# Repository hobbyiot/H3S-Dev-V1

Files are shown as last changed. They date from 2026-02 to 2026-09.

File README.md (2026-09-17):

# H3S-Dev board for building Meshtastic nodes

### The new H3S-Dev design is now in pilot production!

#
## This project is being sponsored by [PCBWay](https://www.pcbway.com/)
### They offer a turnkey service to manufacture and assemble your printed circuit boards! The whole operation is fast and reliable since every single step is agreed between the customer and the responsible people from the factory. Every one detail is discussed as the components and materials used are agreed on at a high professional level.
#

### Specifications:
-  MCU:  ESP32-S3 with 8MB PSRAM
-  LoRa: RA-01SH-P with Power amplifier
-  GNSS: L96-M33 or similar
-  Power: USB-C and additional input (for example solar source) with separate sensing
-  LiPo battery management
-  I2C extension slots and soldering area
-  Credit card size 2-layer PCB
-  KiCad design open source hardware
#

### As a successor of our recent [H2S-Dev board](https://github.com/hobbyiot/LoRa-Nodes) the new hardware is compatible with both Meshtastic and Helium networks, ready to setup a simple node, sensor or tracker of your choice!

#
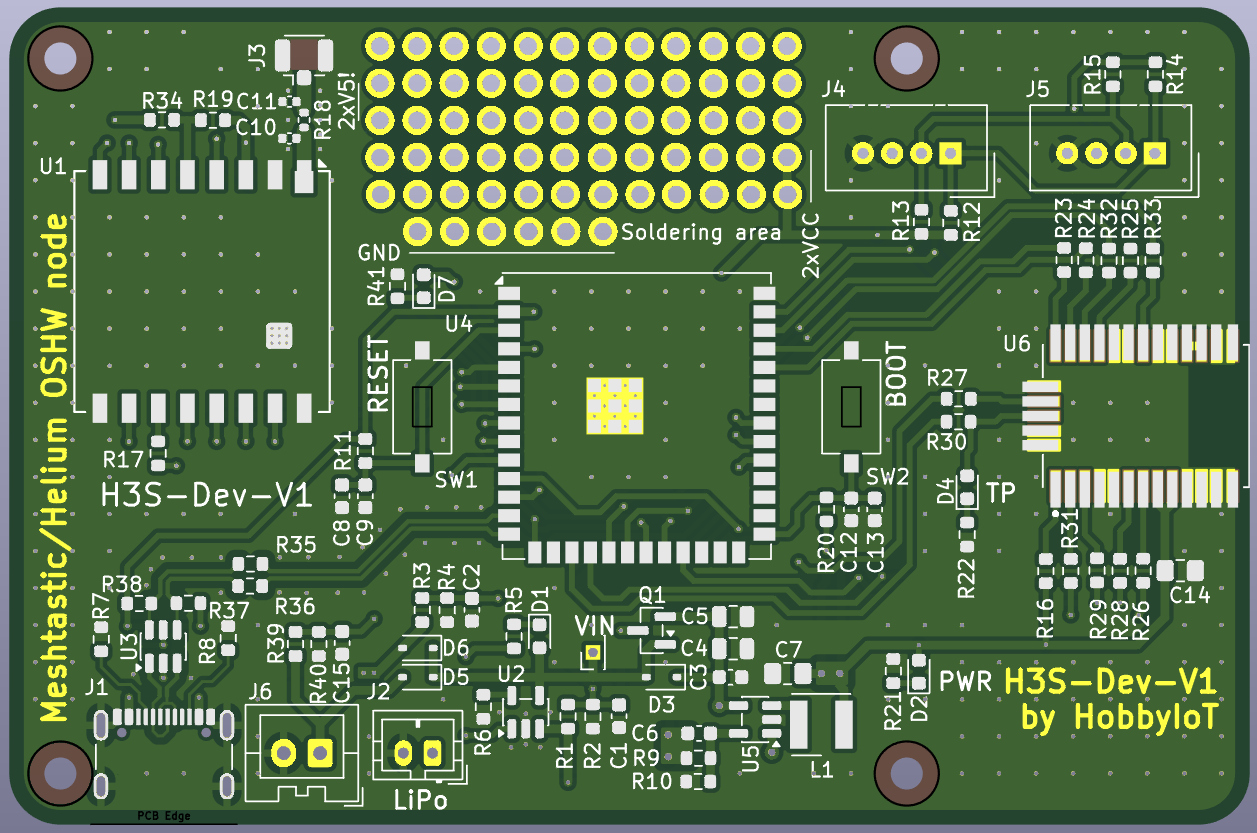
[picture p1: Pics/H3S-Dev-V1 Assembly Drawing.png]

#
### Circuit schematic:


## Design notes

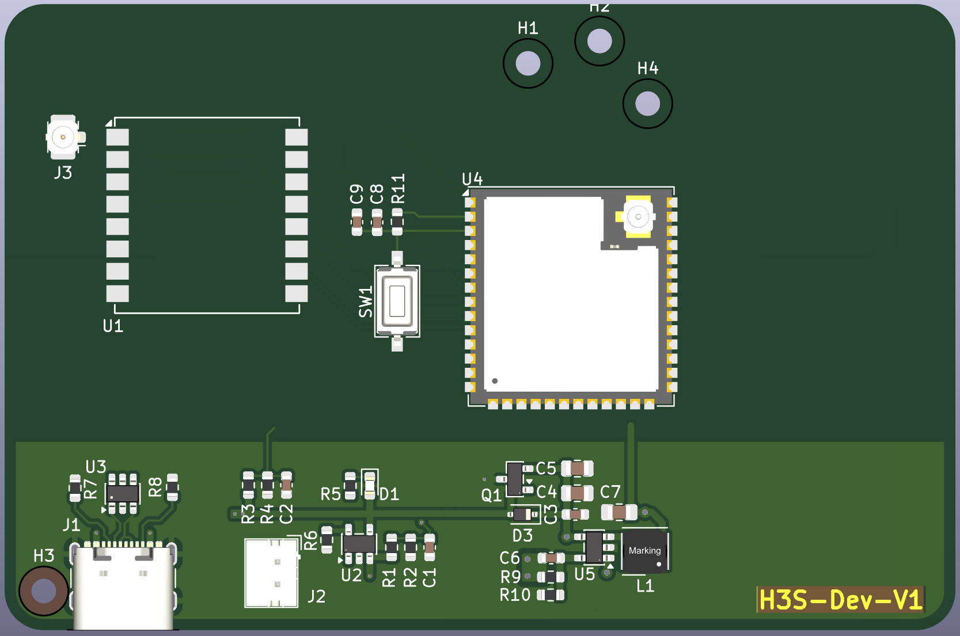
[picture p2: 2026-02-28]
Pics/H3S-Dev WiP 20260227.png

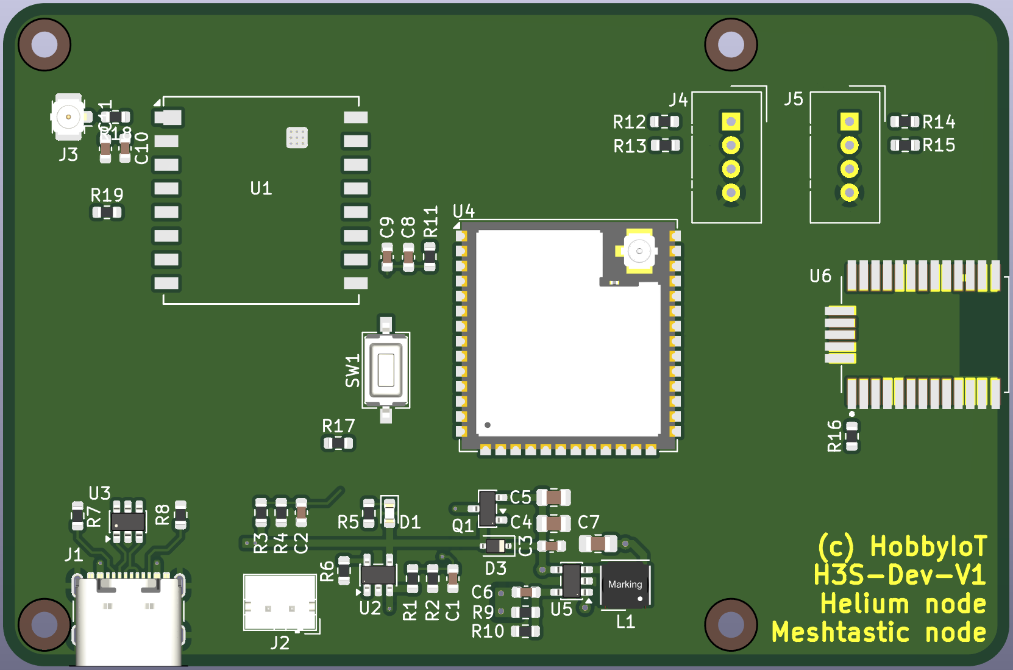
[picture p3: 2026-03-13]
Pics/H3S-Dev WiP 03.png

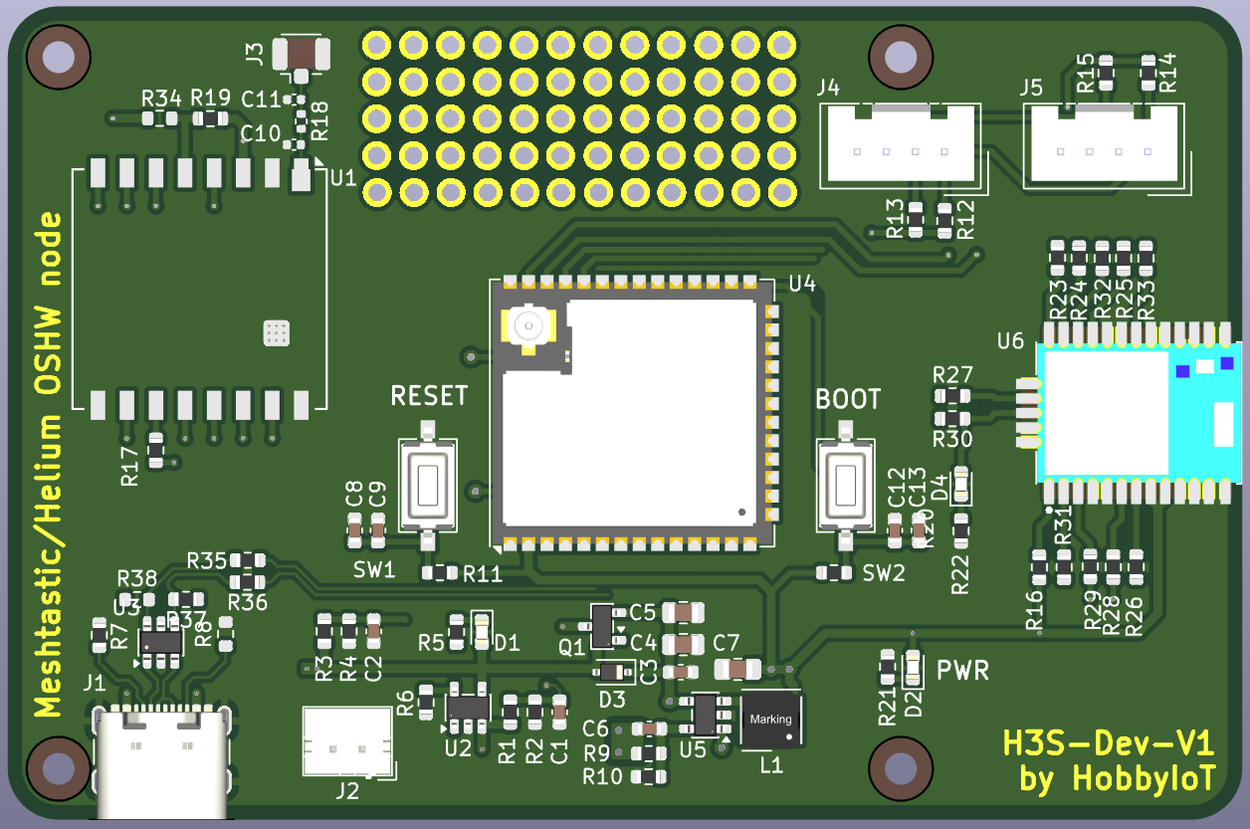
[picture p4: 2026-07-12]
Pics/H3S-Dev WiP 20260712.png

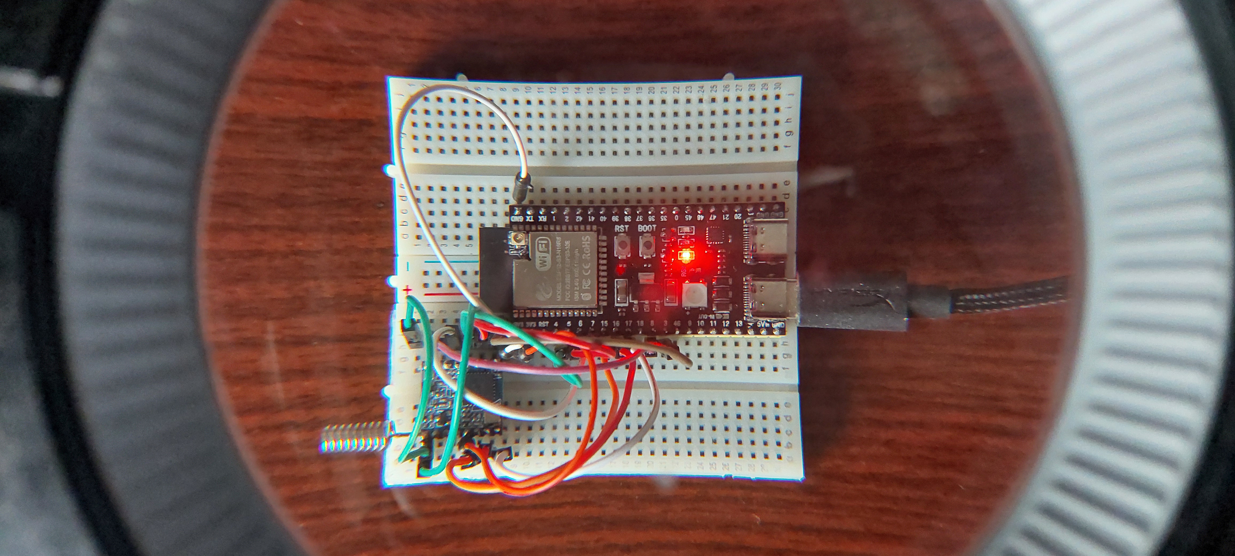
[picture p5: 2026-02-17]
Pics/H2S M ESP32 S3 BB 01.jpg

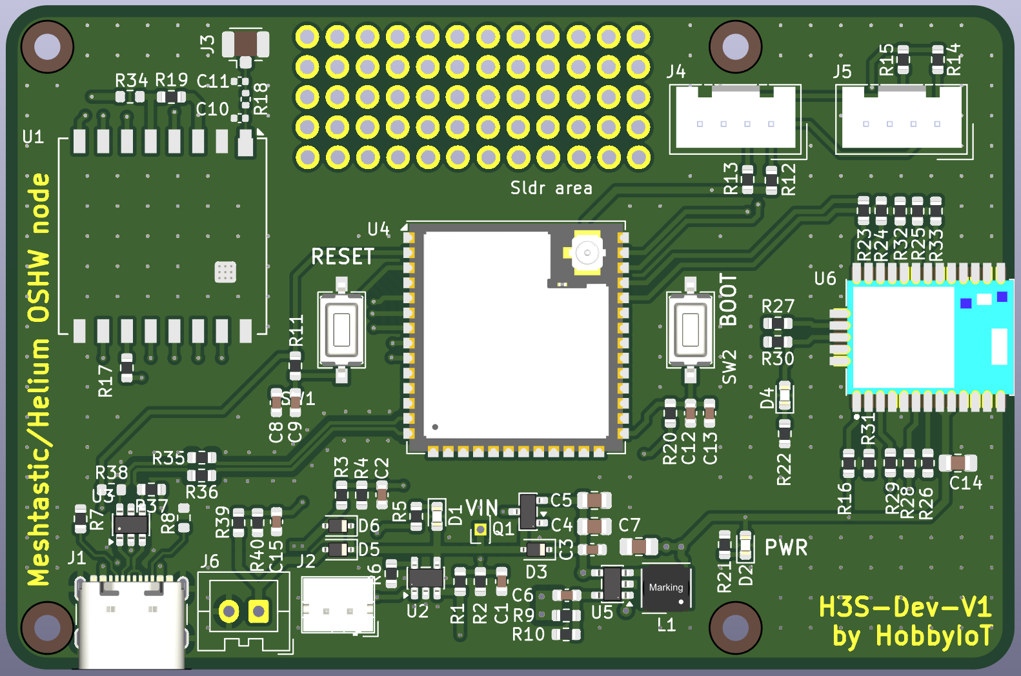
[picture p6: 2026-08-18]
Pics/H3S-Dev PCB 3D Almost.png

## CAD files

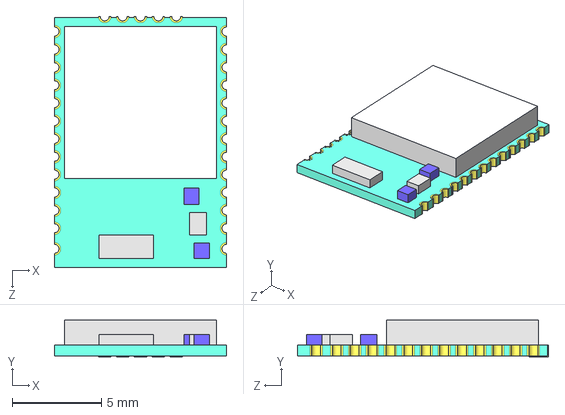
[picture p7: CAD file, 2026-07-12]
HW/H3S-Dev-V1/Models/Quectel L96.STEP
9.62 x 2.05 x 14.1 mm

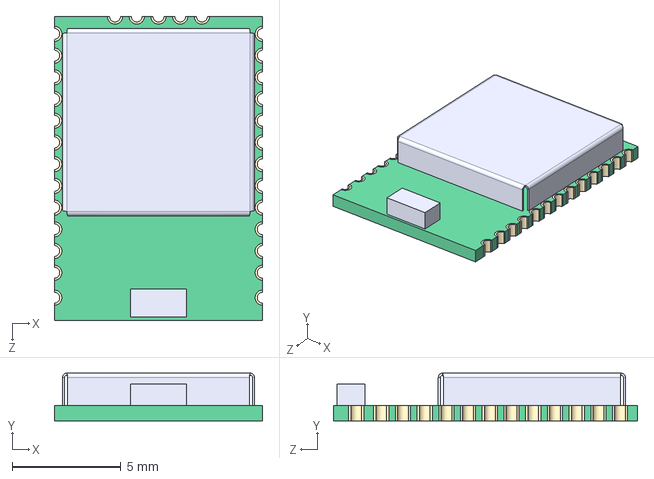
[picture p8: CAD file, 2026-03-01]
HW/HW_Libs/L96_M33/L96-M33.step
9.60 x 2.20 x 14.0 mm

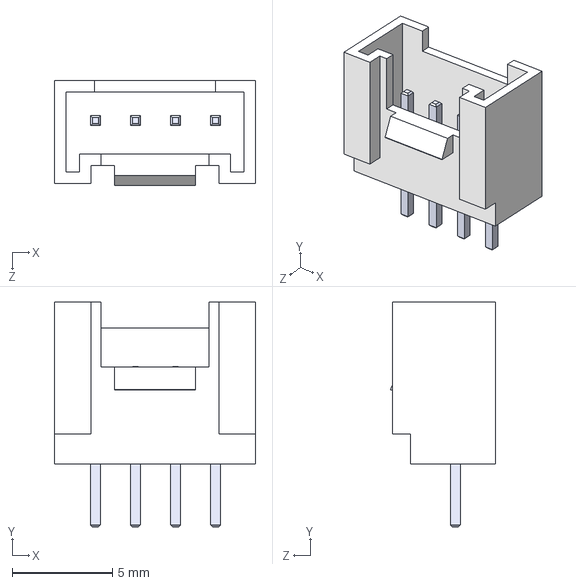
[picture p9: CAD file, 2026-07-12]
HW/H3S-Dev-V1/Models/Grove.STEP
10.1 x 11.2 x 5.25 mm
grove_plastika
pin x 4

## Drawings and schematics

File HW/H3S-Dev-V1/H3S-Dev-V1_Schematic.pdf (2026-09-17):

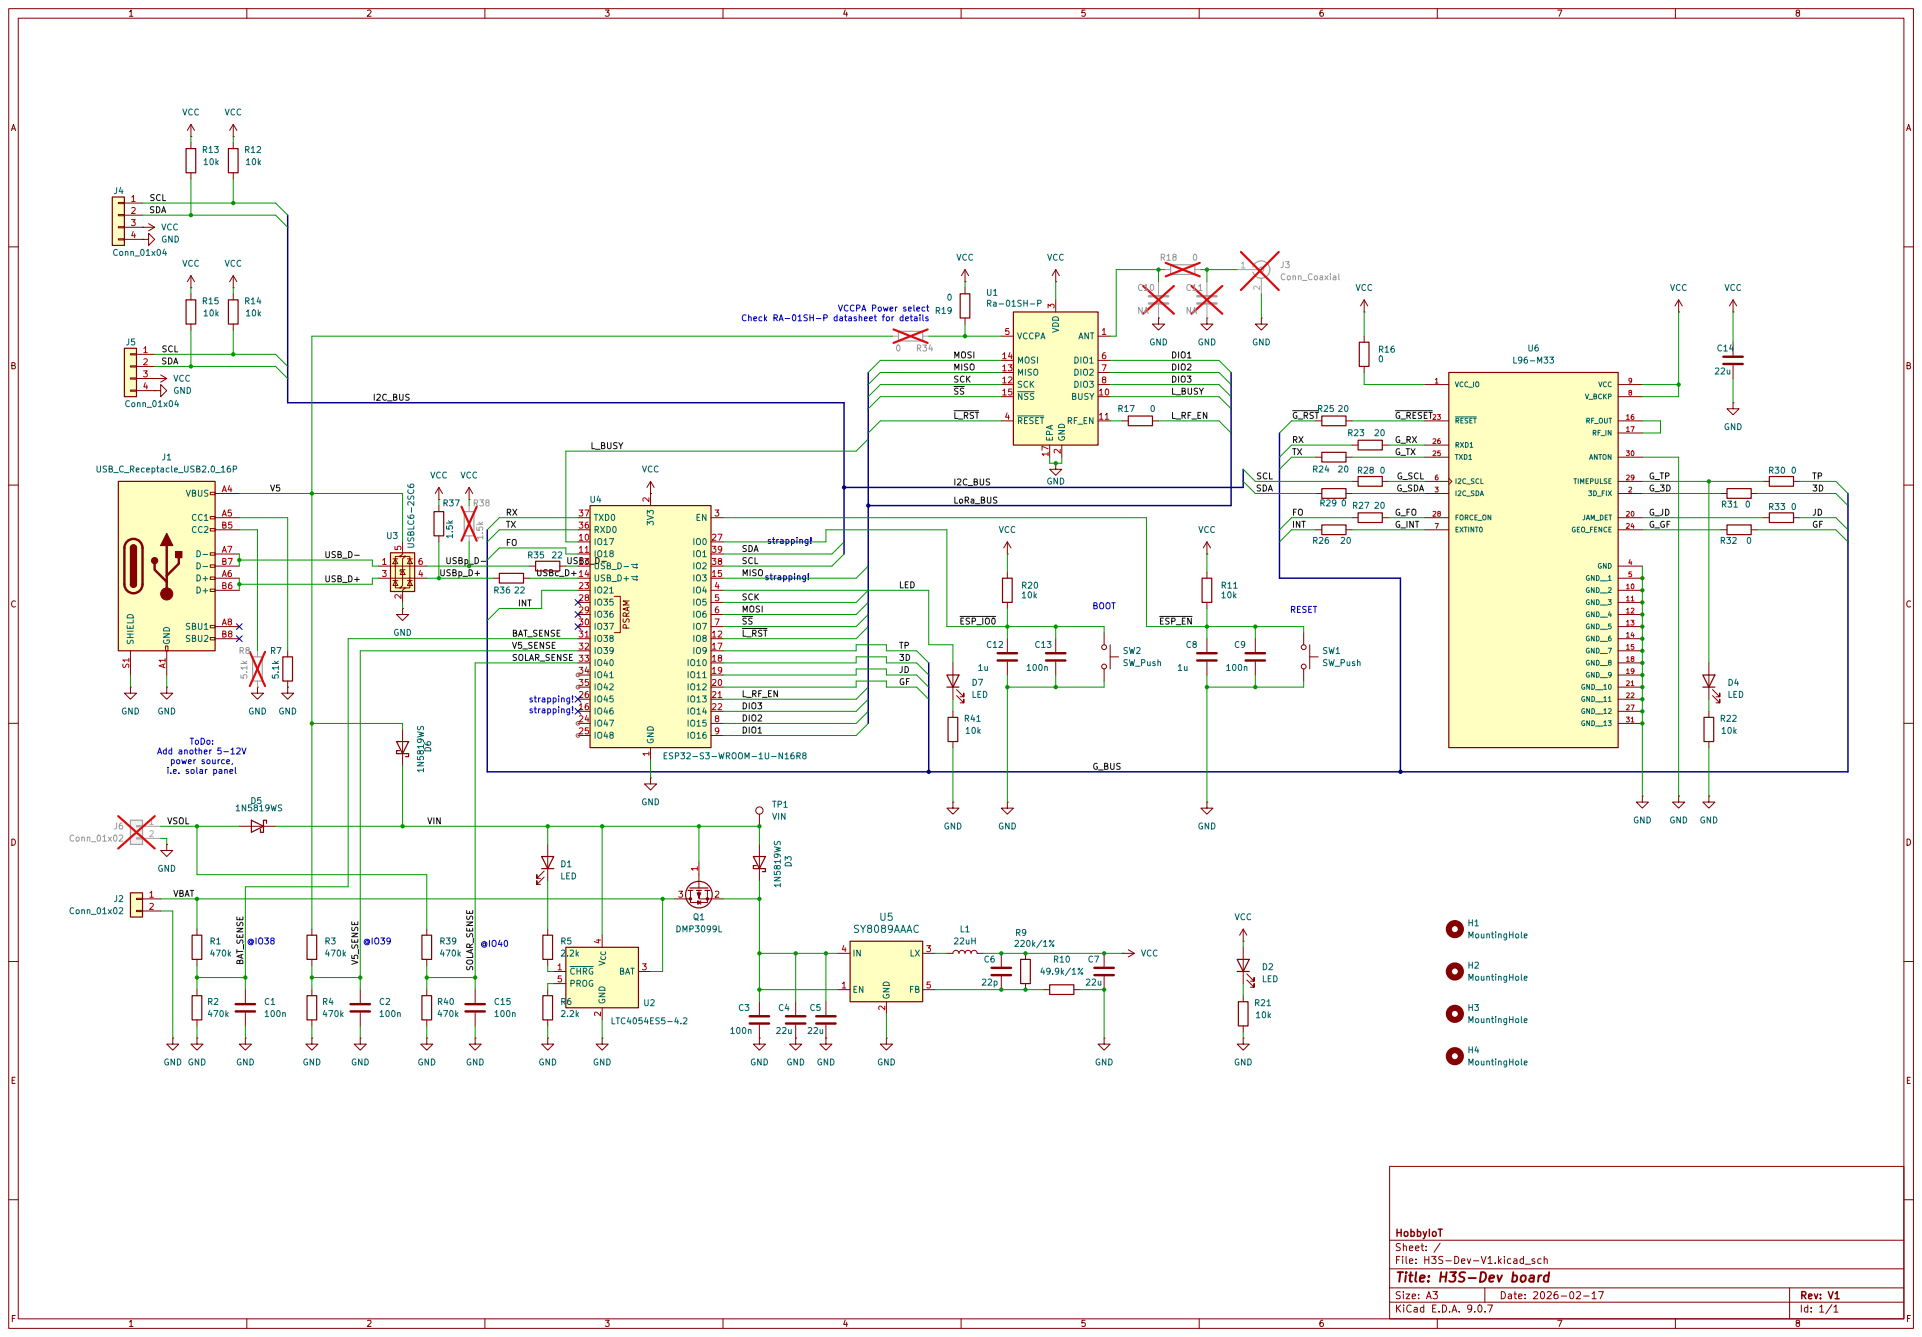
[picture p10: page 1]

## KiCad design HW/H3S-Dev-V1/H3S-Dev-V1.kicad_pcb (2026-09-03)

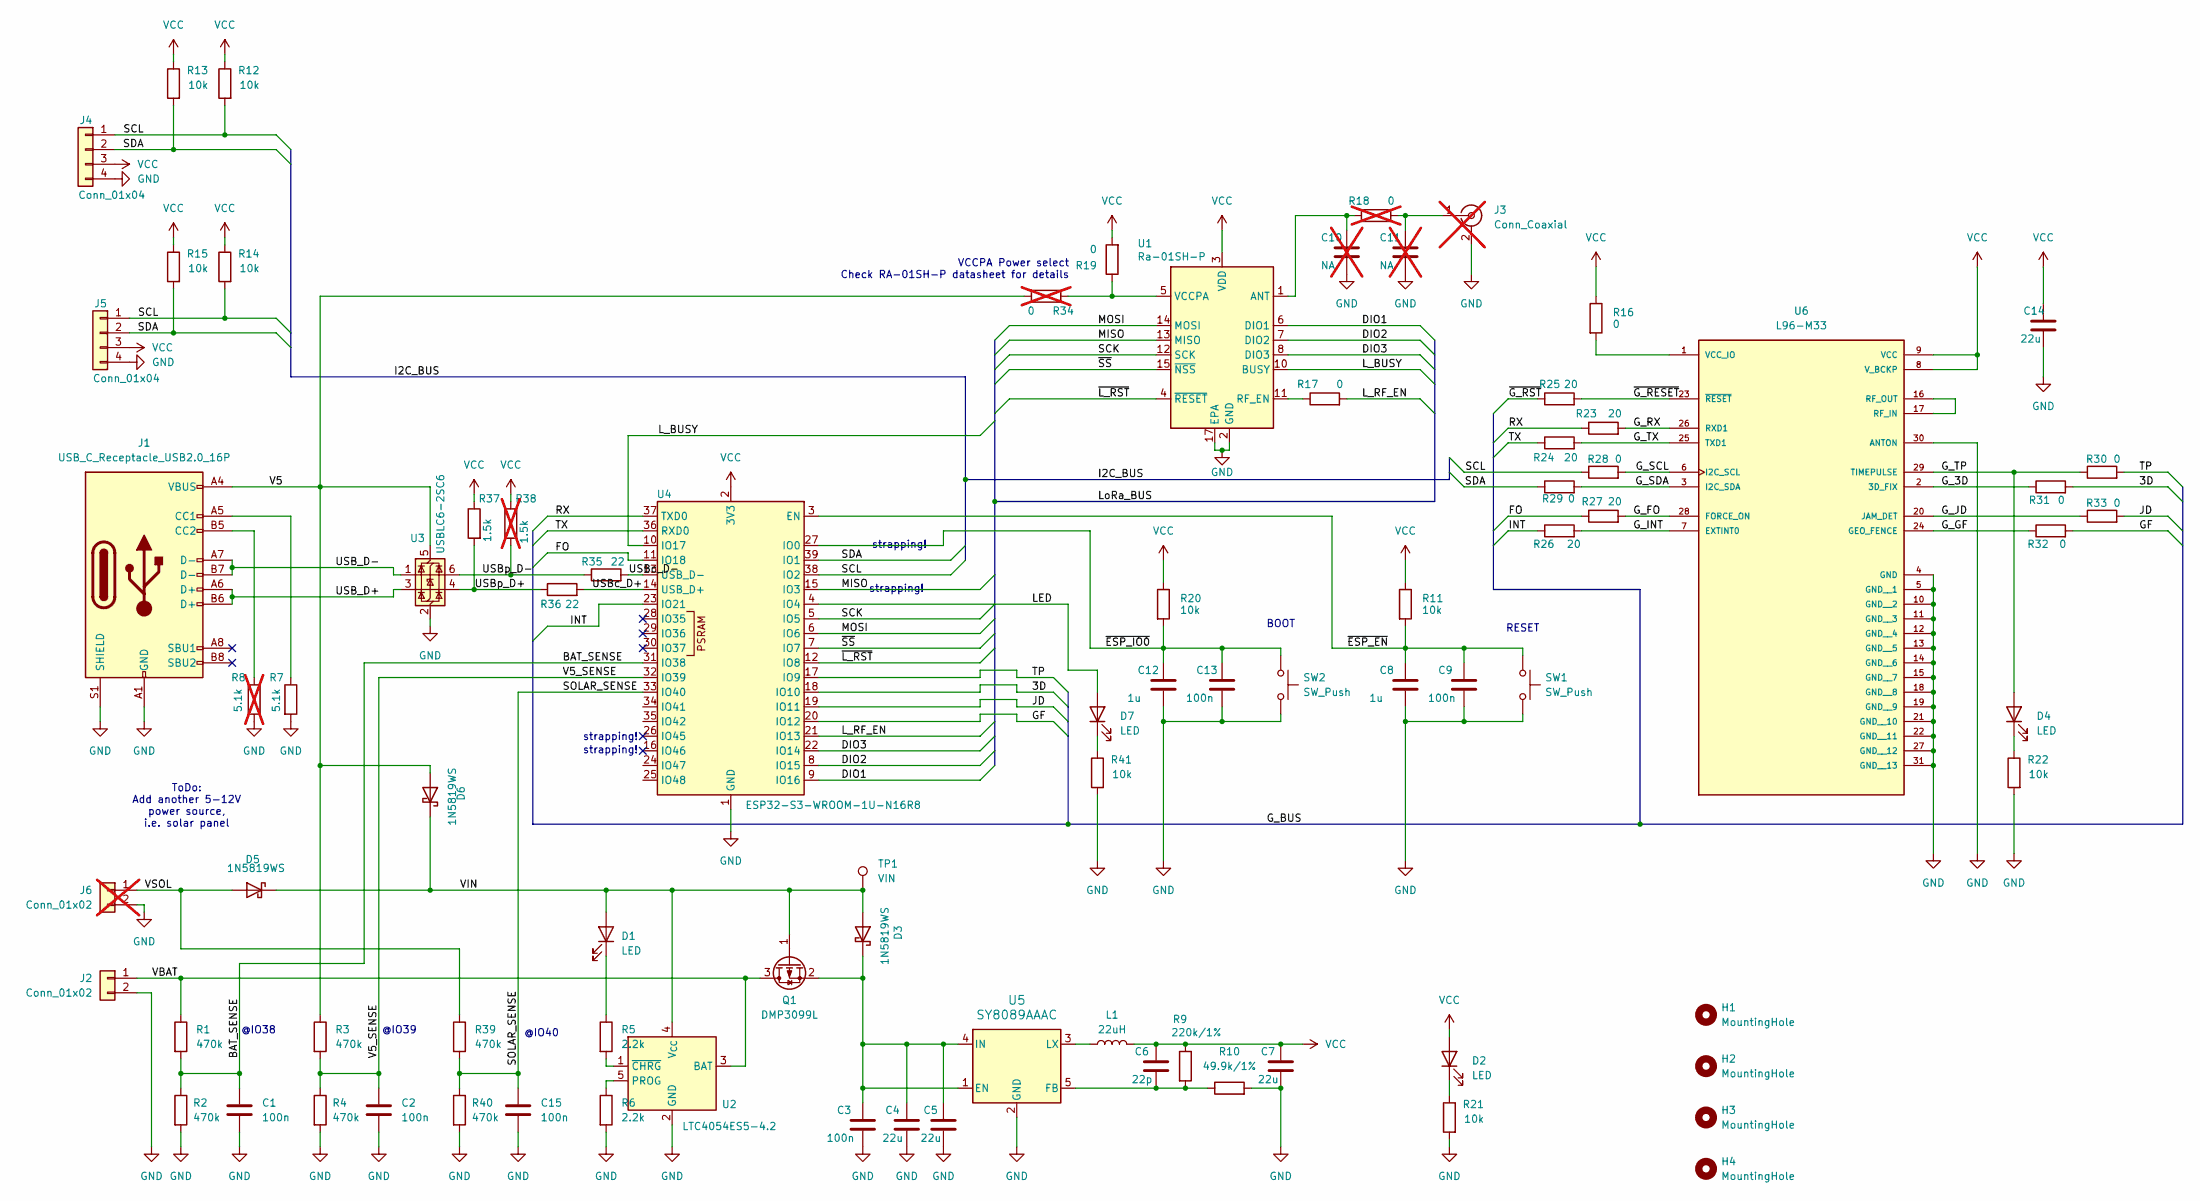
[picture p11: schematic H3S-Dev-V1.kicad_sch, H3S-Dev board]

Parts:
C1, C2, C3, C9, C13, C15: 100n; C_0603_1608Metric
C4, C5: 22u; C_0805_2012Metric
C6: 22p; C_0603_1608Metric
C7, C14: 22u; C_0805_2012Metric_Pad1.18x1.45mm_HandSolder
C8, C12: 1u; C_0603_1608Metric
C10, C11: NA; C_0402_1005Metric; not fitted
D1, D2, D4, D7: LED; LED_0603_1608Metric
D3, D5, D6: 1N5819WS; D_SOD-323
H1, H2, H3, H4: MountingHole; MountingHole_2.2mm_M2
J1: USB_C_Receptacle_USB2.0_16P; USB_C_Receptacle_GCT_USB4105-xx-A_16P_TopMnt_Horizontal
J2: Conn_01x02; JST_PH_B2B-PH-K_1x02_P2.00mm_Vertical
J3: Conn_Coaxial; U.FL_Hirose_U.FL-R-SMT-1_Vertical; not fitted
J4, J5: Conn_01x04; NS-Tech_Grove_1x04_P2mm_Vertical
J6: Conn_01x02; JST_XA_B02B-XASK-1_1x02_P2.50mm_Vertical; not fitted
L1: 22uH; L_Wurth_WE-LQSH-4020
Q1: DMP3099L; SOT-23
R1, R2, R3, R4, R39, R40: 470k; R_0603_1608Metric
R5, R6: 2.2k; R_0603_1608Metric
R7: 5.1k; R_0603_1608Metric
R8: 5.1k; R_0603_1608Metric; not fitted
R9: 220k/1%; R_0603_1608Metric
R10: 49.9k/1%; R_0603_1608Metric
R11, R12, R13, R14, R15, R20, R21, R22, R41: 10k; R_0603_1608Metric
R16, R17, R19, R28, R29, R30, R31, R32, R33: 0; R_0603_1608Metric
R18: 0; R_0402_1005Metric; not fitted
R23, R24, R25, R26, R27: 20; R_0603_1608Metric
R34: 0; R_0603_1608Metric; not fitted
R35, R36: 22; R_0603_1608Metric
R37: 1.5k; R_0603_1608Metric
R38: 1.5k; R_0603_1608Metric; not fitted
SW1, SW2: SW_Push; SW_Tactile_SPST_NO_Straight_CK_PTS636Sx25SMTRLFS
TP1: VIN; PinHeader_1x01_P1.27mm_Vertical
U1: Ra-01SH-P
U2: LTC4054ES5-4.2; TSOT-23-5
U3: USBLC6-2SC6; SOT-23-6
U4: ESP32-S3-WROOM-1U-N16R8; ESP32-S3-WROOM-1U
U5: SY8089AAAC; SOT-23-5
U6: L96-M33; XCVR_L96-M33

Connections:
/3D: R31.2, U4.18 (IO10)
/BAT_SENSE: C1.1, R1.2, R2.1, U4.31 (IO38)
/DIO1: U1.6 (DIO1), U4.9 (IO16)
/DIO2: U1.7 (DIO2), U4.8 (IO15)
/DIO3: U1.8 (DIO3), U4.22 (IO14)
/FO: R27.1, U4.11 (IO18)
/GF: R32.2, U4.20 (IO12)
/G_3D: R31.1, U6.2 (3D_FIX)
/G_FO: R27.2, U6.28 (FORCE_ON)
/G_GF: R32.1, U6.24 (GEO_FENCE)
/G_INT: R26.2, U6.7 (EXTINT0)
/G_JD: R33.1, U6.20 (JAM_DET)
/G_RX: R23.2, U6.26 (RXD1)
/G_SCL: R28.2, U6.6 (I2C_SCL)
/G_SDA: R29.2, U6.3 (I2C_SDA)
/G_TP: D4.2 (A), R30.1, U6.29 (TIMEPULSE)
/G_TX: R24.2, U6.25 (TXD1)
/INT: R26.1, U4.23 (IO21)
/JD: R33.2, U4.19 (IO11)
/LED: D7.2 (A), U4.4 (IO4)
/L_BUSY: U1.10 (BUSY), U4.10 (IO17)
/L_RF_EN: R17.2, U4.21 (IO13)
/MISO: U1.13 (MISO), U4.15 (IO3)
/MOSI: U1.14 (MOSI), U4.6 (IO6)
/RX: R23.1, U4.37 (TXD0)
/SCK: U1.12 (SCK), U4.5 (IO5)
/SCL: J4.1, J5.1, R12.2, R14.2, R28.1, U4.38 (IO2)
/SDA: J4.2, J5.2, R13.2, R15.2, R29.1, U4.39 (IO1)
/SOLAR_SENSE: C15.1, R39.2, R40.1, U4.33 (IO40)
/TP: R30.2, U4.17 (IO9)
/TX: R24.1, U4.36 (RXD0)
/USB_D+: J1.A6 (D+), J1.B6 (D+), U3.3 (I/O2)
/USB_D-: J1.A7 (D-), J1.B7 (D-), U3.1 (I/O1)
/USBc_D+: R36.2, U4.14 (USB_D+)
/USBc_D-: R35.2, U4.13 (USB_D-)
/USBp_D+: R36.1, R37.2, U3.4 (I/O2)
/USBp_D-: R35.1, R38.2, U3.6 (I/O1)
/V5: D6.2 (A), J1.A4 (VBUS), J1.A9 (VBUS), J1.B4 (VBUS), J1.B9 (VBUS), R3.1, R34.2, U3.5 (VBUS)
/V5_SENSE: C2.1, R3.2, R4.1, U4.32 (IO39)
/VBAT: J2.1, Q1.3 (D), R1.1, U2.3 (BAT)
/VIN: D1.2 (A), D3.2 (A), D5.1 (K), D6.1 (K), Q1.1 (G), TP1.1, U2.4 (V_{CC})
/VSOL: D5.2 (A), J6.1, R39.1
/~ESP_EN: C8.1, C9.1, R11.2, SW1.1, U4.3 (EN)
/~ESP_IO0: C12.1, C13.1, R20.2, SW2.1, U4.27 (IO0)
/~G_RESET: R25.2, U6.23 (~RESET)
/~G_RST: R25.1
/~L_RST: U1.4 (~RESET), U4.12 (IO8)
/~SS: U1.15 (~NSS), U4.7 (IO7)
GND: C1.2, C2.2, C3.2, C4.2, C5.2, C7.2, C8.2, C9.2, C10.2, C11.2, C12.2, C13.2, C14.2, C15.2, J1.A1 (GND), J1.A12 (GND), J1.B1 (GND), J1.B12 (GND), J1.S1 (SHIELD), J2.2, J3.2 (Ext), J4.4, J5.4, J6.2, R2.2, R4.2, R6.2, R7.2, R8.2, R10.2, R21.2, R22.2, R40.2, R41.2, SW1.2, SW2.2, U1.2 (GND), U1.9 (GND), U1.16 (GND), U1.17 (EPA), U2.2 (GND), U3.2 (GND), U4.1 (GND), U4.40 (GND), U4.41 (GND), U5.2 (GND), U6.4 (GND), U6.5 (GND__1), U6.10 (GND__2), U6.11 (GND__3), U6.12 (GND__4), U6.13 (GND__5), U6.14 (GND__6), U6.15 (GND__7), U6.18 (GND__8), U6.19 (GND__9), U6.21 (GND__10), U6.22 (GND__11), U6.27 (GND__12), U6.30 (ANTON), U6.31 (GND__13)
unnamed: D1.1 (K), R5.1
unnamed: D2.1 (K), R21.1
unnamed: C3.1, C4.1, C5.1, D3.1 (K), Q1.2 (S), U5.1 (EN), U5.4 (IN)
unnamed: D4.1 (K), R22.1
unnamed: D7.1 (K), R41.1
unnamed: J1.A5 (CC1), R7.1
unnamed: J1.B5 (CC2), R8.1
unnamed: C11.1, J3.1 (In), R18.2
unnamed: C10.1, R18.1, U1.1 (ANT)
unnamed: R17.1, U1.11 (RF_EN)
unnamed: R19.1, R34.1, U1.5 (VCCPA)
unnamed: R6.1, U2.5 (PROG)
unnamed: R5.2, U2.1 (~CHRG)
unnamed: C6.2, R9.2, R10.1, U5.5 (FB)
unnamed: L1.2, U5.3 (LX)
unnamed: U6.16 (RF_OUT), U6.17 (RF_IN)
unnamed: R16.2, U6.1 (VCC_IO)
VCC: C6.1, C7.1, C14.1, D2.2 (A), J4.3, J5.3, L1.1, R9.1, R11.1, R12.1, R13.1, R14.1, R15.1, R16.1, R19.2, R20.1, R37.1, R38.1, U1.3 (VDD), U4.2 (3V3), U6.8 (V_BCKP), U6.9 (VCC)

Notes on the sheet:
@IO38
strapping!
BOOT
ToDo: Add another 5-12V power source, i.e. solar panel
RESET
@IO39
VCCPA Power select Check RA-01SH-P datasheet for details
@IO40

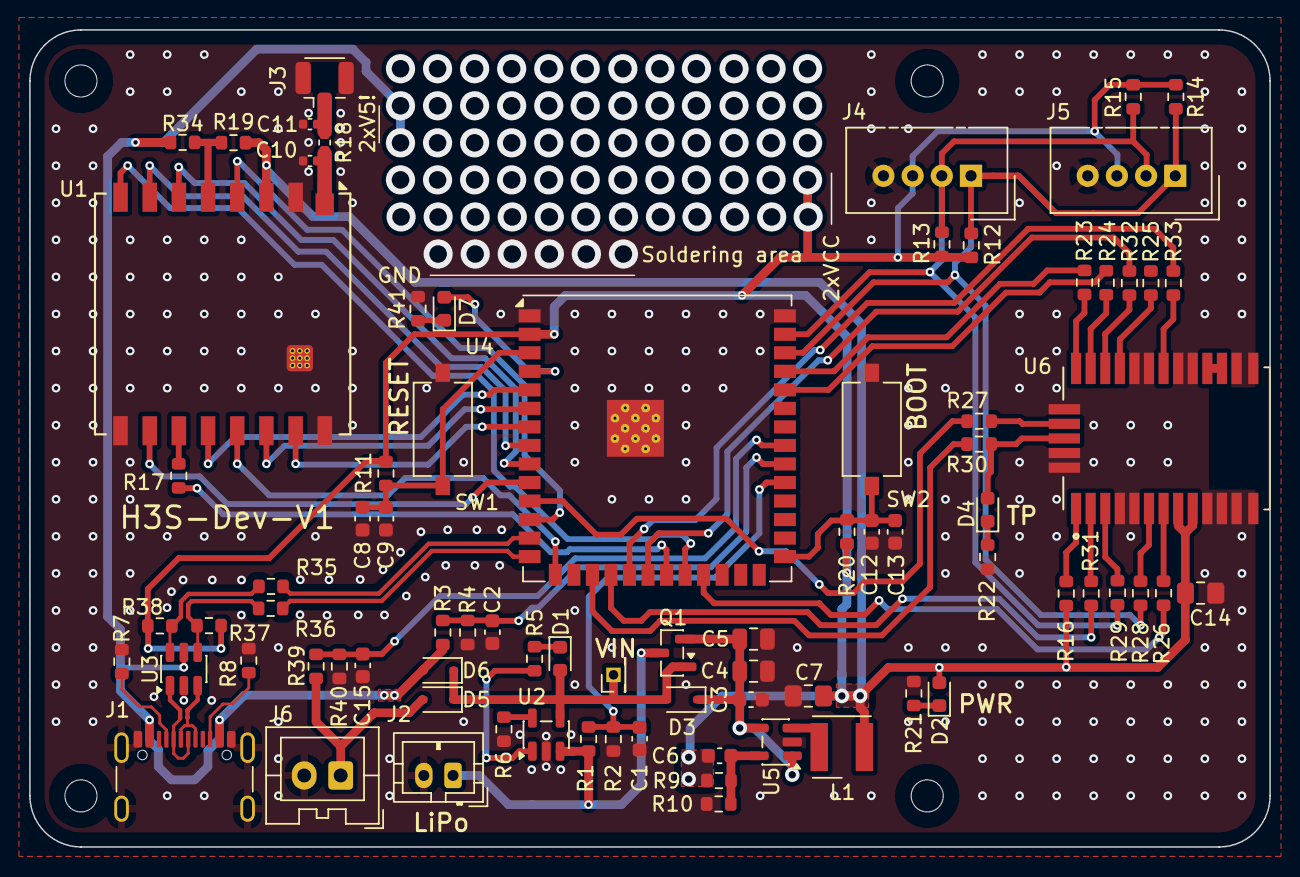
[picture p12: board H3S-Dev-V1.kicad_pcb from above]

Board: 2 copper layers, 85.0 x 56.0 mm, 84 parts (0 on the bottom side), 66 nets.

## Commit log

2026-02-17 USB Updated
    [H3S-Dev-V1.kicad_sch]
2026-02-18 Some components arranged
    [H3S-Dev-V1.kicad_pcb, H3S-Dev-V1.kicad_sch]
2026-02-21 Charger works
    [H3S-Dev-V1.kicad_pcb]
2026-02-22 PCB dimensions
    [H3S-Dev-V1.kicad_pcb]
2026-02-23 dc-dc routing
    [H3S-Dev-V1.kicad_pcb, H3S-Dev-V1.kicad_sch]
2026-02-27 LoRa, Reset and some more routing
    [H3S-Dev-V1.kicad_pcb, H3S-Dev-V1.kicad_sch]
2026-03-01 Some progress ...
    [H3S-Dev-V1.kicad_pcb]
2026-03-01 GNSS Module added
    [H3S-Dev-V1.kicad_pcb, H3S-Dev-V1.kicad_sch]
2026-03-01 GNSS Module models
    [L96-M33.step]
2026-03-05 Some progress...
    [H3S-Dev-V1.kicad_pcb, H3S-Dev-V1.kicad_sch]
2026-03-12 RA-01SH-P LoRa module added
    [H3S-Dev-V1.kicad_pcb, H3S-Dev-V1.kicad_sch]
2026-03-13 J2 updated
    [H3S-Dev-V1.kicad_pcb, H3S-Dev-V1.kicad_sch]
2026-03-13 LoRa updates
    [H3S-Dev-V1.kicad_pcb, H3S-Dev-V1.kicad_sch]
2026-03-13 Footprint updated
2026-03-15 Minor changes
    [H3S-Dev-V1.kicad_pcb, H3S-Dev-V1.kicad_sch]
2026-03-27 Some progress
    [H3S-Dev-V1.kicad_pcb, H3S-Dev-V1.kicad_sch]
2026-05-24 LoRa intereface connected
    [H3S-Dev-V1.kicad_pcb, H3S-Dev-V1.kicad_sch]
2026-07-05 USB link updated
    [H3S-Dev-V1.kicad_sch]
2026-07-08 USB Resistors
    [H3S-Dev-V1.kicad_pcb]
2026-07-11 Routing in progress
    [H3S-Dev-V1.kicad_pcb]
2026-07-12 Grove connector 3D
    [Grove.STEP]
2026-07-12 More progress today
    [H3S-Dev-V1.kicad_pcb, H3S-Dev-V1.kicad_sch]
2026-07-28 USB Diff pair set up
    [H3S-Dev-V1.kicad_pcb, H3S-Dev-V1.kicad_sch]
2026-07-29 USB Diff pair done
    [H3S-Dev-V1.kicad_pcb]
2026-07-30 Routing progress
    [H3S-Dev-V1.kicad_pcb, H3S-Dev-V1.kicad_sch]
2026-08-03 ESP32 Rotated
    [H3S-Dev-V1.kicad_pcb]
2026-08-14 Solar connector added
    [H3S-Dev-V1.kicad_pcb, H3S-Dev-V1.kicad_sch]
2026-08-15 Routing progress...
    [H3S-Dev-V1.kicad_pcb]
2026-08-16 100% routed
    [H3S-Dev-V1.kicad_pcb]
2026-08-18 PCB Almost done
2026-08-18 To review
    [H3S-Dev-V1.kicad_pcb, H3S-Dev-V1.kicad_sch]
2026-08-26 BOM Preparation
    [H3S-Dev-V1.kicad_pcb, H3S-Dev-V1.kicad_sch]
2026-08-29 PCB updates
    [H3S-Dev-V1.kicad_pcb, H3S-Dev-V1.kicad_sch]
2026-09-02 BOM update
    [H3S-Dev-V1.kicad_sch]
2026-09-03 Final updates
    [H3S-Dev-V1.kicad_pcb, H3S-Dev-V1.kicad_sch]
2026-09-17 Schematic PDF
2026-09-17 Schematic SVG
